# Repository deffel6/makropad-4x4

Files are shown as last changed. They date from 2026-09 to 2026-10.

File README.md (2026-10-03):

# Makropad 4 × 4

16 Tasten im 19,05-mm-Raster, Cherry MX, gesteuert von einem Pro Micro über
acht Lötpunkte. Platine **96,2 × 92,2 mm**, zwei Lagen, vollständig verdrahtet.

Platine

Entwurf, Fertigungsdaten und Firmware liegen hier zusammen. Die Platine ist
nicht von Hand gezeichnet, sondern wird aus einem Skript erzeugt — Rastermaß
und Tastenzahl sind dadurch eine Zahl im Kopf der Datei.

## Anschlüsse

Acht durchkontaktierte Lötpunkte in einer Reihe am oberen Rand, im
2,54-mm-Raster. Von links:

```
R3  R2  R1  R0  C0  C1  C2  C3
```

| Lötpunkt | QMK | Aufdruck am Pro Micro | Arduino |
|---|---|---|---|
| `R0` | `D4` | 4 | 4 |
| `R1` | `C6` | 5 | 5 |
| `R2` | `D7` | 6 | 6 |
| `R3` | `E6` | 7 | 7 |
| `C0` | `F4` | A3 | 21 |
| `C1` | `F5` | A2 | 20 |
| `C2` | `F6` | A1 | 19 |
| `C3` | `F7` | A0 | 18 |

Zeilen auf der linken Stiftleiste, Spalten auf der rechten, beide in der
unteren Hälfte des Moduls — so bleiben die Drähte kurz.

**Frei bleiben** `D0`/`D1` (I²C, für ein Display), `D2`/`D3` (seriell),
`B1`/`B2`/`B3` (SPI) sowie `B4`/`B5`/`B6`. Versorgung braucht die Platine
keine: Eine Tastenmatrix wird allein über die acht Signalleitungen abgefragt.

## Verdrahtung

```
Spalte ──── Schalter ──── Diode ──►── Zeile
                          Anode   Kathode
```

Die Diode verhindert Phantomtasten: Ohne sie schließen drei gleichzeitig
gedrückte Tasten einen Pfad über eine vierte, die gar nicht gedrückt ist.
Stromrichtung Spalte → Zeile, in QMK `COL2ROW`.

Spalten laufen senkrecht auf der Vorderseite, Zeilen waagerecht auf der
Rückseite. Weil jeder Lötpunkt auf der Achse seiner Bahn sitzt, kreuzt sich
nichts — die Platine kommt ohne eine einzige Durchkontaktierung aus.

| Vorderseite | Rückseite |
|---|---|
| vorn | hinten |

## Fertigen lassen

`hardware/keypad4x4-gerber.zip` bei einem Hersteller hochladen, nicht
entpacken. Voreinstellungen passen: zweilagig, 1,6 mm, HASL.

Geprüft ist die Platine mit dem Regelprüfer von KiCad 10:

```
Regelverstöße:        0
Unverbundene Stellen: 0
```

Dazu gegengelesen: Jedes der 40 Lötaugen hat eine durchkontaktierte Bohrung,
alle 52 Löcher ohne Kupfer sind vorhanden, 92 Bohrungen gesamt. Das Rastermaß
beträgt überall exakt 19,05 mm — auch von Zapfenloch zu Zapfenloch.

Wer die Dioden bestücken lassen will, findet in `bestueckung/` die Stückliste
und die Positionsdatei. Die 16 SOD-123 sitzen auf der **Unterseite**.

## Stückliste

| Menge | Teil | Hinweis |
|---|---|---|
| 16 | Cherry MX oder kompatibel | **PCB-Bauform mit fünf Beinen** |
| 16 | 1N4148W, SOD-123 | Rückseite, SMD |
| 1 | Pro Micro ATmega32U4 | oder steckkompatibler Ersatz |
| 1 | Stiftleiste 8-polig, 2,54 mm | |
| 4 | M2-Schraube mit Abstandshalter | Löcher Ø 2,2 mm |

Die Schalter brauchen die PCB-montierte Bauform mit zwei Kunststoffzapfen
neben den Kontakten — die Platine hat Löcher dafür. Die Plattenbauform ohne
Zapfen passt zwar hinein, sitzt aber lose.

## Firmware

Wer nicht selbst übersetzen will, nimmt die fertigen Dateien aus
[`firmware/fertig/`](firmware/fertig/) und flasht sie mit der
[QMK Toolbox](https://github.com/qmk/qmk_toolbox/releases) — dafür braucht es
weder QMK noch ein Terminal. Die Anleitung dazu liegt im selben Ordner.

> **Stand der fertigen Dateien:** Die beiden `.hex` stammen noch von der
> früheren Belegung (Zifferblock mit Ebenen-Taste unten rechts) und sind nicht
> neu übersetzt. Die Quellen in `firmware/keypad4x4/` haben bereits die neue
> Belegung mit 16 freien Tasten. Die Vial-Datei ist trotzdem brauchbar, weil
> sich dort jede Taste in der App umbelegen lässt. Die `default`-Datei hat die
> alte feste Belegung, bis sie mit `make keypad4x4:default` neu gebaut wird.

Selbst bauen: `firmware/keypad4x4/` nach `keyboards/` in QMK oder vial-qmk
kopieren, dann:

```
make keypad4x4:default          # feste Belegung
make keypad4x4:vial             # zur Laufzeit änderbar
```

Beide Fassungen sind übersetzt und geprüft:

| | Größe | Auslastung |
|---|---|---|
| default | 15.808 Bytes | 55 % |
| vial | 28.246 Bytes | 98 % |

Die Vial-Fassung passt nur knapp: Der Pro Micro hat nach Abzug des
Bootloaders 28.672 Bytes, und Vial bringt viel mit. In
`keymaps/vial/rules.mk` ist deshalb alles Entbehrliche abgeschaltet und die
Zahl der Ebenen auf drei begrenzt. **Für Erweiterungen ist kein Platz mehr.**
Wer mehr will, nimmt ein RP2040-Modul in Pro-Micro-Bauform — es passt auf
dieselben Lötpunkte und hat das Sechzehnfache an Speicher.

### ZMK mit ZMK Studio (nice!nano, kabellos)

Alternativ zum Pro Micro mit QMK: ein **nice!nano** auf denselben acht
Lötpunkten, Firmware in ZMK. Belegung wie oben, aber im Browser änderbar
(<https://zmk.studio>, Chrome oder Edge) und ohne Speicherproblem — der
nRF52840 hat 1 MB Flash. Die Dateien liegen im Wurzelverzeichnis
(`config/`, `boards/`, `build.yaml`), weil ZMKs GitHub-Build sie dort erwartet;
den Build startet ein Push, die `.uf2` liegt danach unter *Actions → Artifacts*.

| Lötpunkt | Pro-Micro-Pin |
|---|---|
| `R0` `R1` `R2` `R3` | 4 · 5 · 6 · 7 |
| `C0` `C1` `C2` `C3` | A3 (21) · A2 (20) · A1 (19) · A0 (18) |

Der Akku hängt direkt an `B+`/`B−` des nice!nano, die Platine hat keinen
Anschluss dafür. Studio ist nicht gesperrt (`CONFIG_ZMK_STUDIO_LOCKING=n` in
`config/keypad4x4.conf`), eine Entsperr-Taste braucht es also nicht und alle 16
Tasten bleiben frei. Dafür kann jeder Rechner, an dem das Pad per USB hängt,
die Belegung ändern. Wer das nicht will, setzt die Option auf `y` und legt
`&studio_unlock` auf eine Taste.

### Belegung

Alle 16 Tasten sind Programmtasten auf einer einzigen Ebene. Keine ist für einen
Ebenenwechsel oder die Studio-Entsperrung reserviert.

```
F13      F14      F15      F16
F17      F18      F19      F20
F21      F22      F23      F24
Meh+F13  Meh+F14  Meh+F15  Meh+F16
```

`F13` bis `F24` gibt es auf keiner gewöhnlichen Tastatur, und genau deshalb
sind sie brauchbar: Kein Programm belegt sie schon. Werkzeuge wie Hammerspoon
oder die Kurzbefehle-App können sie frei binden. Mehr als zwölf freie F-Tasten
kennt der USB-Standard nicht, deshalb liegen in der untersten Reihe `F13` bis
`F16` mit **Meh** (Strg + Umschalt + Alt) — in Hammerspoon `{"ctrl","alt","shift"}`.

Jede Taste lässt sich umbelegen: in ZMK mit Studio im Browser, in der
Vial-Fassung mit der Vial-App. Die frühere Belegung als Zifferblock mit
Ebenen-Taste ist damit ersetzt. Wer sie zurück will, legt sie in Studio oder
Vial wieder an und opfert dafür eine Taste als Ebenenschalter.

## Ändern

```bash
cd hardware && python3 generate_pcb.py && python3 preview.py
```

Oben in `generate_pcb.py` stehen `COLS`, `ROWS` und `PITCH`. Auf 5 × 4 oder
ein engeres Raster umzustellen ist eine Zeile — Platinengröße,
Bauteilpositionen und alle Leiterbahnen werden daraus gerechnet.

`preview.py` liest dabei die **erzeugte Platinendatei**, nicht die Absicht des
Generators. Ein Schreibfehler fällt dadurch im Bild auf, statt unbemerkt zu
bleiben. `gerber_render.py` geht noch einen Schritt weiter und zeichnet die
ausgelieferten Gerber- und Bohrdateien selbst — also das, was beim Hersteller
ankommt.

## Werkzeuge

KiCad 10 zum Ansehen und Bearbeiten, Python 3 für die Skripte, QMK oder
vial-qmk für die Firmware. Die Fußabdrücke stehen vollständig in der
Platinendatei, sie braucht also keine Bibliothek.

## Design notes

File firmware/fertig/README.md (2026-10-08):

# Fertige Firmware

Übersetzt und einsatzbereit — zum Flashen brauchst du weder QMK noch ein
Terminal, die [QMK Toolbox](https://github.com/qmk/qmk_toolbox/releases)
genügt.

Hier liegen drei Dateien: zwei für das Pro-Micro-Keypad (QMK/Vial) und
eine für das nice!nano-Keypad (ZMK). Welche zu welchem Gerät gehört, steht
in der Tabelle.

| Datei | Gerät | Belegung |
|---|---|---|
| `keypad4x4_default.hex` | Pro Micro (ATmega32U4) | fest eingebaut, 15.808 Bytes (55 %) |
| `keypad4x4_vial.hex` | Pro Micro (ATmega32U4) | über Vial änderbar, 28.246 Bytes (98 %) |
| `keypad4x4_zmk.uf2` | nice!nano (nRF52840) | über ZMK Studio änderbar |

Die `.uf2` entsteht sonst nur als Artefakt eines GitHub-Actions-Laufs, und
die verfallen nach einiger Zeit. Deshalb liegt hier eine Kopie des jeweils
aktuellen Standes.

## Welche nehmen

**vial** für den Normalfall. Du änderst die Belegung dann in der Vial-App,
ohne je wieder zu flashen.

**default**, wenn du Vial nicht brauchst. Sie lässt 12 KB frei, in denen
später Erweiterungen Platz hätten — die Vial-Fassung ist mit 98 Prozent
randvoll.

## Flashen des nice!nano

Viel einfacher als beim Pro Micro — kein Programm nötig:

1. **Akku abziehen**, nur das USB-Kabel angesteckt lassen
2. **RST und GND zweimal kurz hintereinander** verbinden, im Takt eines
   Doppelklicks
3. Es erscheint ein Laufwerk **NICENANO**
4. `keypad4x4_zmk.uf2` daraufziehen

Das Board schreibt die Datei selbst, startet neu, und das Laufwerk
verschwindet. Die Fehlermeldung, die macOS dabei zeigt, gehört dazu: Das
Board hängt sich mitten im Schreiben selbst aus.

> **Wichtig:** Wurde die Belegung je in ZMK Studio geändert, liegt sie im
> Speicher des Keypads und **überstimmt die Firmware** — auch nach dem
> Flashen. Dann in ZMK Studio einmal **"Restore Stock Settings"** auslösen.

Der Akku muss ab, weil der Doppeltipp sonst oft nicht als zwei getrennte
Resets ankommt.

## Flashen mit der QMK Toolbox

1. Toolbox öffnen, oben über **Open** die `.hex`-Datei laden
2. Bei *MCU* **atmega32u4** wählen
3. Häkchen bei **Auto-Flash** setzen
4. Den **Reset**-Anschluss des Pro Micro **zweimal kurz hintereinander** auf
   Masse legen

Im Fenster erscheint dann grün „Caterina device connected", und der Vorgang
läuft von allein. Er dauert wenige Sekunden.

Das Zeitfenster ist kurz: Der Pro Micro meldet sich nach dem doppelten Reset
nur etwa acht Sekunden lang als Programmiergerät, danach startet er die
vorhandene Firmware. Deshalb das Häkchen bei *Auto-Flash* — sonst musst du
den Knopf in dieser Zeitspanne selbst treffen.

## Wenn nichts passiert

**Kein „Caterina device connected"** — der doppelte Reset war zu langsam
oder zu schnell. Zwei zügige Berührungen, etwa im Takt eines Doppelklicks.

**Beim ersten Flashen eines frischen Pro Micro** genügt oft ein einfacher
Reset, weil das Modul noch leer ist und ohnehin im Bootloader steht.

**Falscher Anschluss** — gemeint ist `RST` gegen `GND`, beide liegen auf der
rechten Stiftleiste nebeneinander.

## Prüfsummen

```
995e3e11b5357333569727529e88326333cffb72e6cc32e93cd0ee714375d42d  keypad4x4_default.hex
bea514d3c68f86d1b647a75fa26ab12ef3849a9da4298091c78cee10ecf70edc  keypad4x4_vial.hex
9e20bb151ac78a56d79cec0044b7cbb6d23fc76bdfa691837d731a94cf97e753  keypad4x4_zmk.uf2
```

Die Prüfsummen gelten für den Stand vom 8. Oktober 2026. Nach jedem
Neubau ändern sie sich.

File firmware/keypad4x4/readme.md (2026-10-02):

# keypad4x4

16 Tasten im 4×4-Raster, Cherry MX, Pro Micro über acht Lötpunkte
angeschlossen. Passend zur Platine aus `~/keypad-4x4`.

## Anschluss

| Lötpunkt auf der Platine | Pin am Pro Micro |
|---|---|
| `C0` `C1` `C2` `C3` | `F4` `F5` `F6` `F7` |
| `R0` `R1` `R2` `R3` | `D4` `C6` `D7` `E6` |

Dioden in Richtung Spalte → Zeile, in QMK also `COL2ROW`.

## Übersetzen und flashen

```
cd ~/vial-qmk
make keypad4x4:default          # feste Belegung
make keypad4x4:vial             # zur Laufzeit änderbar
```

Flashen mit angehängtem `:flash`, also `make keypad4x4:vial:flash`. Der Pro
Micro meldet sich nur ein paar Sekunden lang als Programmiergerät — dafür
den Reset-Anschluss **zweimal kurz hintereinander** auf Masse legen, sobald
in der Ausgabe „Detecting USB port" erscheint.

## Die beiden Belegungen

**default** — eine einzige Ebene, fest eingebaut. Alle 16 Tasten sind
Programmtasten: `F13` bis `F24` in den ersten drei Reihen, in der untersten
`F13` bis `F16` mit Strg+Umschalt+Alt (`MEH`). Keine Taste ist für einen
Ebenenwechsel reserviert. Größe: nach der früheren Belegung rund 55 % des
Speichers, die neue Fassung ist noch nicht gemessen.

**vial** — dieselbe Grundbelegung auf Ebene 0, aber über die Vial-App
änderbar, ohne neu zu übersetzen. Die Ebenen 1 und 2 sind leer. Entsperrt wird
mit den beiden oberen linken Tasten gleichzeitig.

## Warum F13 bis F24

Diese Tasten gibt es auf keiner gewöhnlichen Tastatur, und genau deshalb
sind sie nützlich: Kein Programm hat sie schon belegt. In Hammerspoon oder
der Kurzbefehle-App lassen sie sich frei binden, ohne mit bestehenden
Tastenkombinationen zu kollidieren.

## Speicherplatz

Der Pro Micro hat 32 KB Flash, davon belegt der Caterina-Bootloader vier —
es bleiben **28.672 Bytes**.

Die Vial-Fassung füllt davon 98 %. Damit sie überhaupt hineinpasst, sind in
`keymaps/vial/rules.mk` alle entbehrlichen Funktionen abgeschaltet und die
Zahl der Ebenen auf drei begrenzt.

**Das heißt: Für Erweiterungen ist kein Platz mehr.** Wer Tap Dance, Combos
oder eine vierte Ebene will, braucht einen Controller mit mehr Flash — ein
RP2040-Modul in Pro-Micro-Bauform etwa passt auf dieselben Lötpunkte und
bringt das Sechzehnfache mit.

Die **default**-Fassung hat dagegen reichlich Luft.

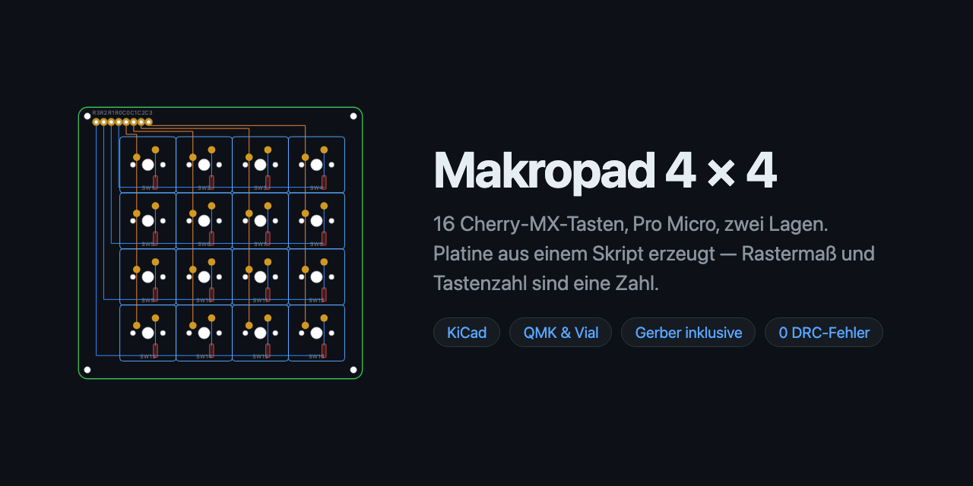
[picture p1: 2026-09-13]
hardware/bilder/repo-vorschau.png

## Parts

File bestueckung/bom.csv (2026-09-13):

Comment | Designator | Footprint | LCSC Part Number
1N4148W | D1,D2,D3,D4,D5,D6,D7,D8,D9,D10,D11,D12,D13,D14,D15,D16 | SOD-123 | C2099

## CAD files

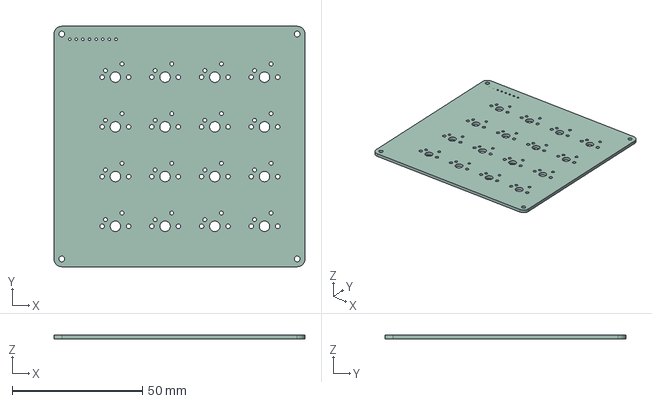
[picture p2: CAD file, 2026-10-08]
hardware/keypad4x4.step
96.2 x 92.2 x 1.51 mm

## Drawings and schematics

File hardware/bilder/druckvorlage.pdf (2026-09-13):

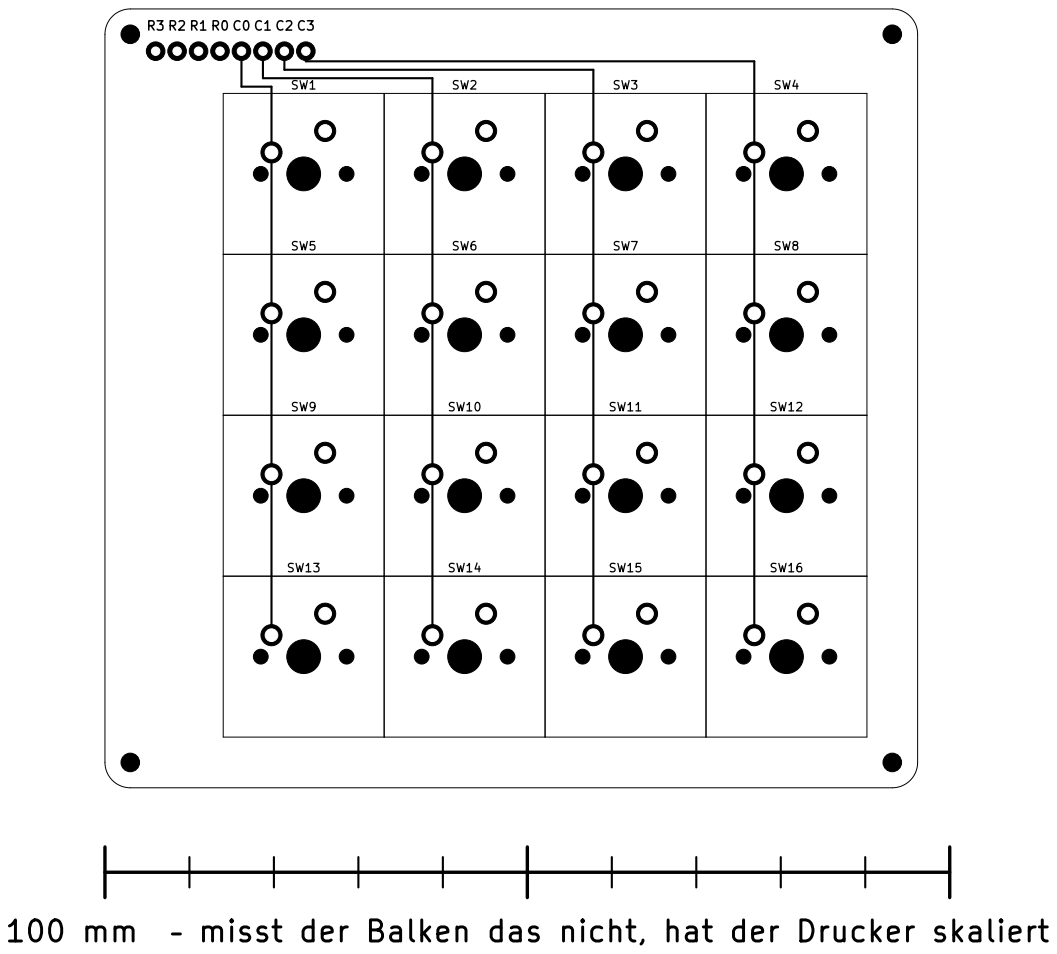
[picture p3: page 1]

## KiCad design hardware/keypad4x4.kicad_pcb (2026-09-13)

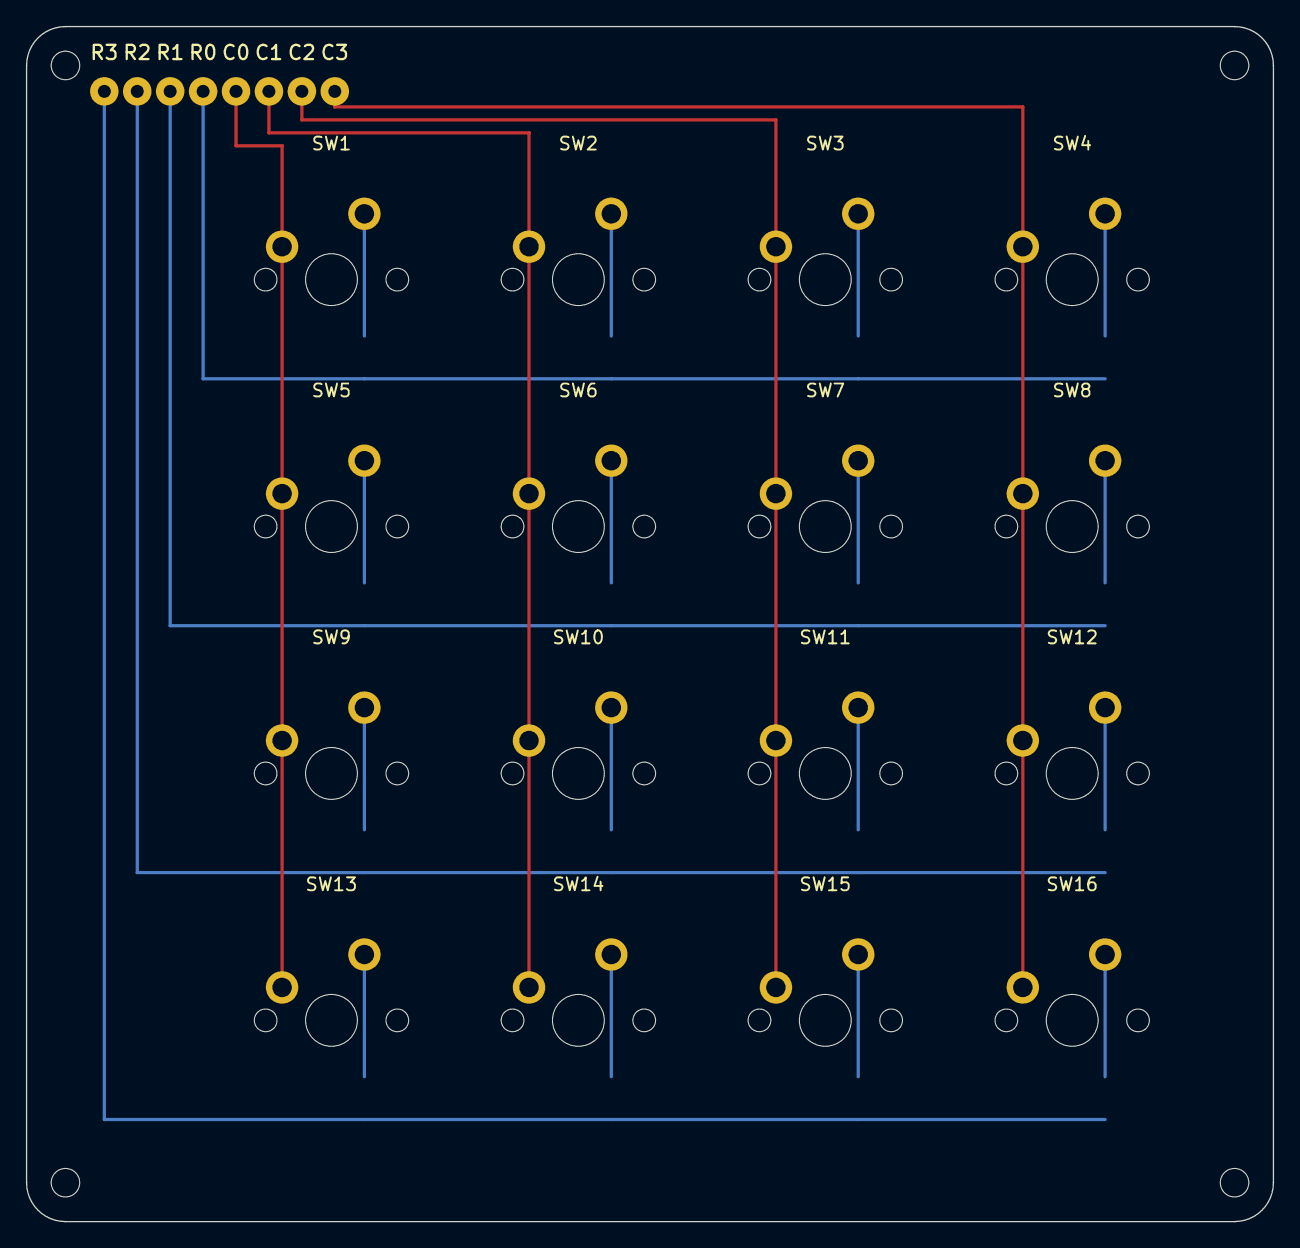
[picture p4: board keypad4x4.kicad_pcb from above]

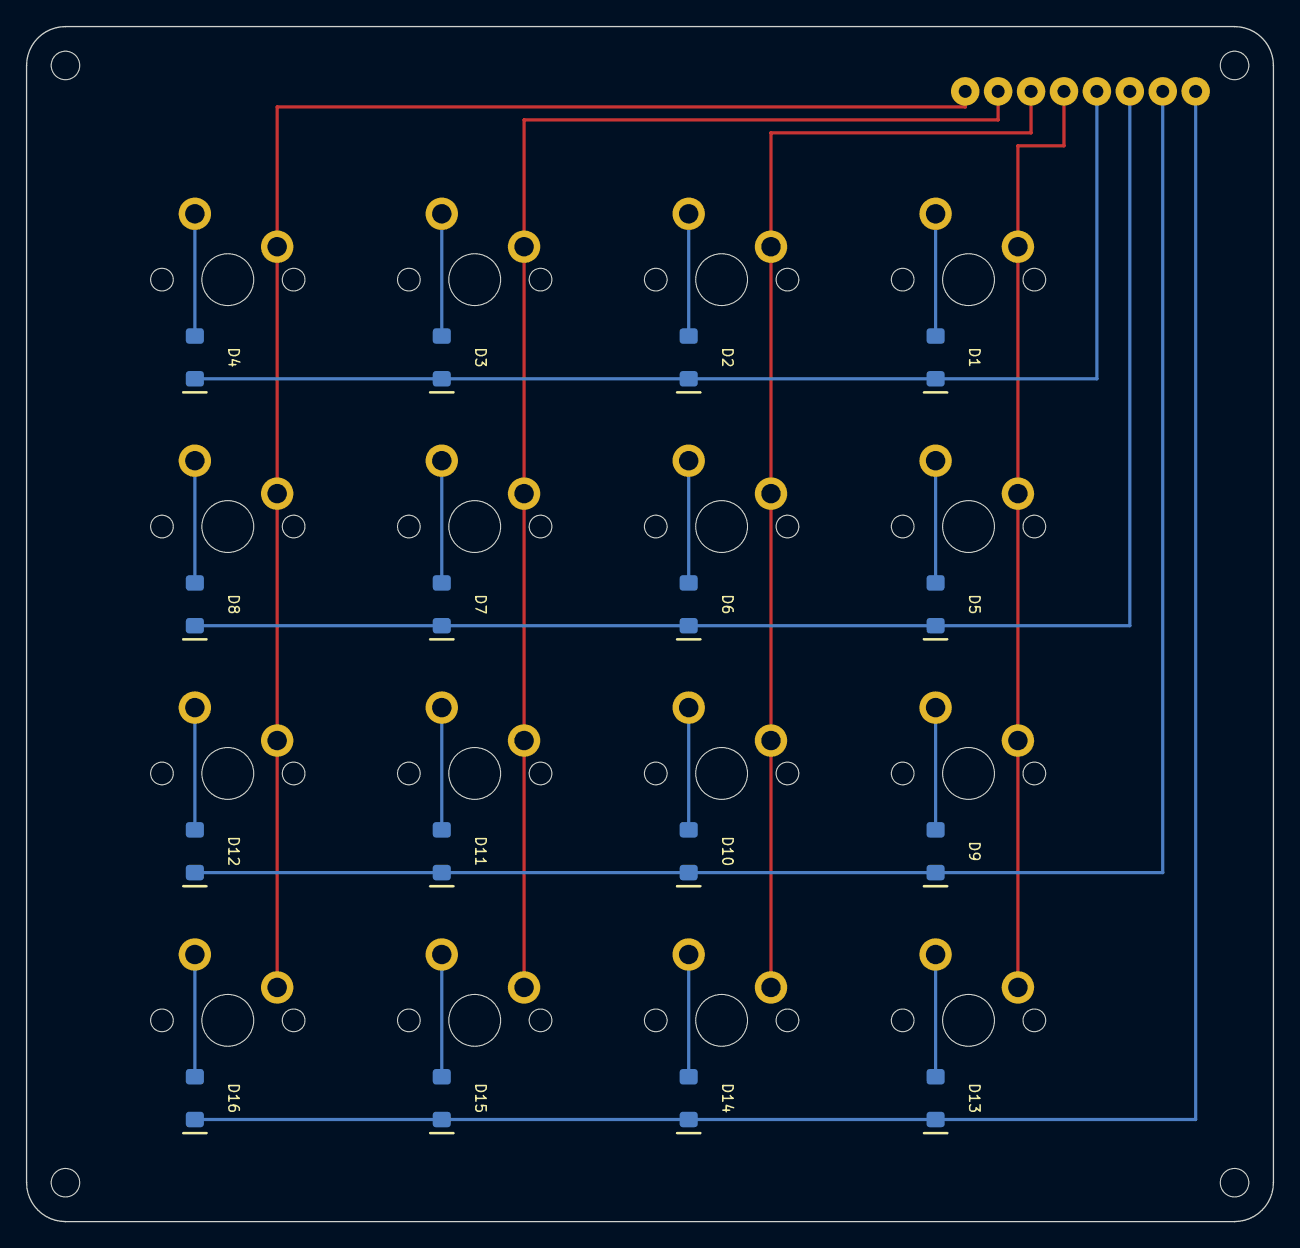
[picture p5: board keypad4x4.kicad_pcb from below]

Board: 2 copper layers, 96.2 x 92.2 mm, 40 parts (16 on the bottom side), 24 nets.

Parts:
D1, D2, D3, D4, D5, D6, D7, D8, D9, D10, D11, D12, D13, D14, D15, D16: 1N4148W; D_SOD-123
J1, J2, J3, J4, J5, J6, J7, J8: Pad
SW1, SW2, SW3, SW4, SW5, SW6, SW7, SW8, SW9, SW10, SW11, SW12, SW13, SW14, SW15, SW16: MX; MX_1u

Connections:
COL0: J5.1, SW1.1, SW5.1, SW9.1, SW13.1
COL1: J6.1, SW2.1, SW6.1, SW10.1, SW14.1
COL2: J7.1, SW3.1, SW7.1, SW11.1, SW15.1
COL3: J8.1, SW4.1, SW8.1, SW12.1, SW16.1
ROW0: D1.1, D2.1, D3.1, D4.1, J4.1
ROW1: D5.1, D6.1, D7.1, D8.1, J3.1
ROW2: D9.1, D10.1, D11.1, D12.1, J2.1
ROW3: D13.1, D14.1, D15.1, D16.1, J1.1
SW1_D: D1.2, SW1.2
SW2_D: D2.2, SW2.2
SW3_D: D3.2, SW3.2
SW4_D: D4.2, SW4.2
SW5_D: D5.2, SW5.2
SW6_D: D6.2, SW6.2
SW7_D: D7.2, SW7.2
SW8_D: D8.2, SW8.2
SW9_D: D9.2, SW9.2
SW10_D: D10.2, SW10.2
SW11_D: D11.2, SW11.2
SW12_D: D12.2, SW12.2
SW13_D: D13.2, SW13.2
SW14_D: D14.2, SW14.2
SW15_D: D15.2, SW15.2
SW16_D: D16.2, SW16.2

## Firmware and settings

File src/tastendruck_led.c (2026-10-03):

/*
 * Blaue LED des nice!nano (P0.15) als Tastenanzeige.
 *
 * Ab Werk blinkt die LED dauerhaft. Dieses Modul nimmt sie in Besitz:
 * beim Start wird sie ausgeschaltet, und jeder Tastendruck laesst sie
 * kurz aufleuchten. Losgelassen wird nicht beachtet - sonst wuerde die
 * LED bei langem Halten zweimal blitzen.
 *
 * Die Dauer steht in CONFIG_TASTENDRUCK_LED_MS (Vorgabe 40 ms). Ein
 * einzelner verzoegerter Auftrag genuegt: Kommt waehrend des Leuchtens
 * der naechste Tastendruck, verschiebt k_work_reschedule nur dessen
 * Ablaufzeit, statt einen zweiten Auftrag anzulegen.
 */

#include <zephyr/kernel.h>
#include <zephyr/device.h>
#include <zephyr/drivers/gpio.h>
#include <zephyr/init.h>

#include <zmk/event_manager.h>
#include <zmk/events/position_state_changed.h>

static const struct gpio_dt_spec tasten_led =
	GPIO_DT_SPEC_GET(DT_NODELABEL(led_tastendruck), gpios);

static void led_aus(struct k_work *work)
{
	ARG_UNUSED(work);
	gpio_pin_set_dt(&tasten_led, 0);
}

static K_WORK_DELAYABLE_DEFINE(led_aus_auftrag, led_aus);

static int tastendruck_beobachter(const zmk_event_t *eh)
{
	const struct zmk_position_state_changed *ev = as_zmk_position_state_changed(eh);

	if (ev != NULL && ev->state) {
		gpio_pin_set_dt(&tasten_led, 1);
		k_work_reschedule(&led_aus_auftrag, K_MSEC(CONFIG_TASTENDRUCK_LED_MS));
	}

	/* Das Ereignis muss weiterlaufen, sonst kommt kein Tastendruck an. */
	return ZMK_EV_EVENT_BUBBLE;
}

ZMK_LISTENER(tastendruck_led, tastendruck_beobachter);
ZMK_SUBSCRIPTION(tastendruck_led, zmk_position_state_changed);

static int tastendruck_led_init(void)
{
	if (!gpio_is_ready_dt(&tasten_led)) {
		return -ENODEV;
	}

	/* INACTIVE = aus. Damit ist das Blinken ab dem Start weg. */
	return gpio_pin_configure_dt(&tasten_led, GPIO_OUTPUT_INACTIVE);
}

SYS_INIT(tastendruck_led_init, APPLICATION, CONFIG_APPLICATION_INIT_PRIORITY);

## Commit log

2026-09-13 Makropad 4x4: Platine, Fertigungsdaten und Firmware
    16 Cherry-MX-Tasten im 19,05-mm-Raster an einem Pro Micro, angeschlossen
    ueber acht Loetpunkte in einer Reihe am oberen Rand.
    Die Platine wird nicht von Hand gezeichnet, sondern aus einem Skript
    erzeugt. Rastermass, Spalten- und Zeilenzahl stehen als Konstanten im Kopf
    von generate_pcb.py; Platinengroesse, Bauteilpositionen und saemtliche
    Leiterbahnen werden daraus gerechnet. Eine Umstellung auf 5x4 oder ein
    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
    [bom.csv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]
2026-09-13 Vorschaubild: aufgedruckte Beschriftung statt Referenzbezeichner
    Die acht Anschlusspunkte trugen im Bild J1 bis J8 - das ist ihr interner
    Bezeichner, auf der Platine steht aber R3 bis C3. Wer das Bild neben die
    gefertigte Platine legt, sucht nach der aufgedruckten Beschriftung, nicht
    nach der internen.
    preview.py bevorzugt jetzt den Siebdrucktext, wo einer vorhanden ist. Bei
    Schaltern und Dioden aendert sich nichts, die tragen keinen.
    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
2026-09-13 Fertige Firmware zum Flashen mit der QMK Toolbox
    Bisher musste man QMK einrichten und selbst uebersetzen, um die Tastatur in
    Betrieb zu nehmen. Das ist eine hohe Huerde fuer jemanden, der nur die
    Platine nachbauen will.
    Beide Fassungen liegen jetzt uebersetzt bei, samt Anleitung fuer die QMK
    Toolbox und Pruefsummen.
    Gegengelesen im Intel-HEX-Format: keine Pruefsummenfehler, und die
    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
2026-10-03 Keypad heisst jetzt Agent Thilo 4*4 Matrix
    Der Name steht in keyboard.json (USB-Produktname, den Vial und macOS
    anzeigen) und in vial.json. VID, PID und die Vial-UID bleiben gleich,
    Vial erkennt das Geraet also weiter und die Belegung bleibt erhalten.
    Die Vial-Firmware ist neu gebaut: 28.246 Bytes, 426 Bytes frei.
2026-10-03 Fertige Firmware neu gebaut: 16 freie Tasten waren nicht drin
    Der Commit 'Alle 16 Tasten als freie Programmtasten' hat nur die
    keymap.c geaendert, nicht die .hex-Dateien unter firmware/fertig.
    Wer die dort liegende Firmware geflasht hat, bekam weiter die alte
    Belegung. Beide Fassungen sind jetzt aus dem aktuellen Quelltext
    gebaut, inklusive des neuen Geraetenamens.
    default 15.808 Bytes (55 %), vial 28.246 Bytes (98 %).
2026-10-03 Blaue LED blitzt bei Tastendruck statt dauernd zu blinken
    Die blaue LED des nice!nano (P0.15) blinkte im Betrieb durchgehend.
    Im ZMK-Quelltext steuert sie niemand, sie kommt also aus einer
    Voreinstellung. Das Modul nimmt sie jetzt in Besitz: beim Start aus,
    bei jedem Tastendruck 40 ms an.
    Dafuer wird das Repo vom reinen Board-Modul zum vollen Zephyr-Modul
    (zephyr/CMakeLists.txt und zephyr/Kconfig). Die LED steht eigens im
    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
2026-10-03 Bau: ZMK-Kopfdateien aus app/include einbinden
    Der Bau brach mit 'zmk/event_manager.h: No such file or directory' ab.
    Modulen gibt ZMK nur app/module/include mit, die uebrigen Kopfdateien
    liegen in app/include und mussten ausdruecklich dazu.
2026-10-06 Belegung: alle 16 Tasten auf Umschalt+Alt rechts mit F1 bis F16
    Loest F13 bis F24 und die Meh-Reihe ab. Fortlaufend von oben links
    nach unten rechts, damit die Zuordnung Taste zu Kuerzel offensichtlich
    bleibt.
    Umschalt+Alt+F-Taste tippt niemand versehentlich und erzeugt kein
    Zeichen - jede Taste ist damit ein eindeutiger Ausloeser. Ziffern
    schieden aus, davon gibt es nur zehn.
2026-10-06 Zurueck auf F13 bis F24
    Die Zwischenfassung mit Umschalt+Alt+F1..F16 ist raus. F1 bis F12 liegen
    auf Helligkeit, Lautstaerke und Mission Control, und Ziffern mit Alt
    erzeugen auf dem Mac Sonderzeichen. F13 bis F24 belegt dagegen nichts,
    und sie tippen kein Zeichen.
    Die Begruendung steht jetzt im Kopfkommentar, samt dem Hinweis, dass
    ohne 'Restore Stock Settings' in ZMK Studio keine Datei wirkt.
2026-10-06 Belegung: Strg+Befehl mit 0-9 und F1-F6
    Loest F13 bis F24 ab. Vom Nutzer so gewaehlt und am Mac geprueft
    (Key Codes zeigte ^⌘0 sauber an).
    Strg+Befehl+Ziffer ist auf dem Mac praktisch unbelegt, tippt sich nicht
    versehentlich und erzeugt kein Sonderzeichen. Damit laesst sich die
    Belegung ohne Zusatzprogramm in der Kurzbefehle-App zuweisen.
2026-10-06 Belegung: blanke F1 bis F16
    Loest Strg+Befehl mit Ziffern ab. Vom Nutzer so gewuenscht.
    Im Kopfkommentar steht der Hinweis, dass F1 bis F12 auf dem Mac mit
    Helligkeit, Mission Control und Lautstaerke belegt sind, solange in den
    Systemeinstellungen nicht 'F1, F2 usw. als Standardfunktionstasten
    verwenden' eingeschaltet ist.
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2026-10-08 STEP der Platine fuers Gehaeuse
    Direkt aus keypad4x4.kicad_pcb exportiert (kicad-cli, --board-only), also
    masshaltig: Umriss 96,2 x 92,2 mm mit 3 mm Eckradius, alle Bohrungen,
    Platinendicke.
    Wichtig fuers Gehaeuse: Das Tastenfeld sitzt NICHT mittig auf der
    Platine. Seine Mitte liegt bei X 72,10 / Y 68,10, die Platinenmitte bei
    X 68,10 / Y 66,10 - also 4 mm weiter rechts und 2 mm weiter unten.
    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
    [keypad4x4.step]
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
